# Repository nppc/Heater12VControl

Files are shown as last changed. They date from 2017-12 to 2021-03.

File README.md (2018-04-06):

# uReflow Station
Micro Reflow Station with 12V heating ceramic element and temperature PID control.

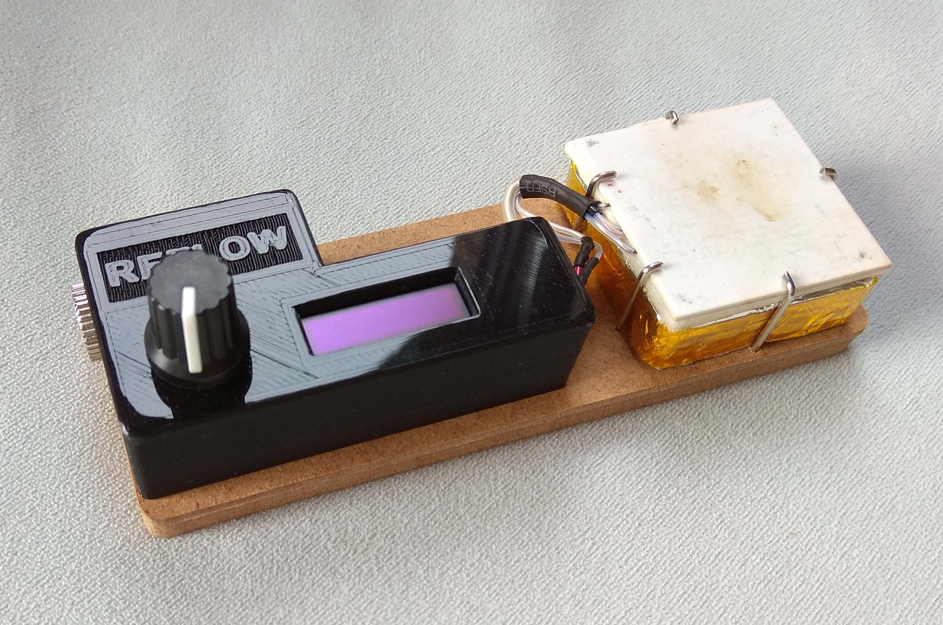
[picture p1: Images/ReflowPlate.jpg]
Device assembled

The device is only 13cm long. Heating plate is 4x4cm. Power is 12VDC.

## 2 modes of operation: Manual and Automatic.
In Manual mode preset temperature is maintained. The temperature can be adjusted on the fly.
In Automatic mode the device is following general reflow thermal profile.

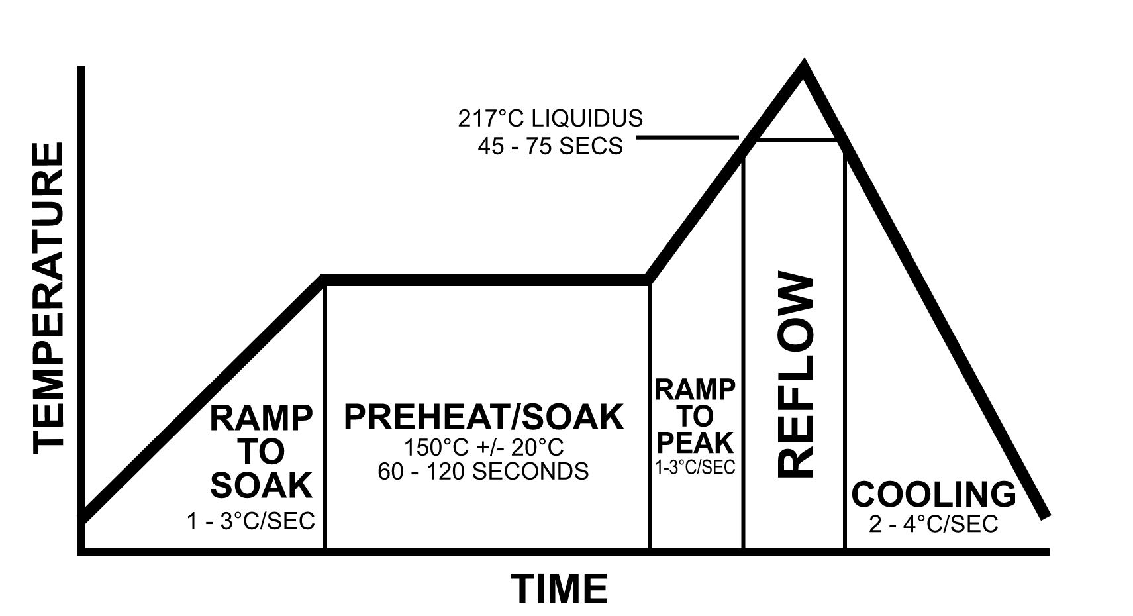
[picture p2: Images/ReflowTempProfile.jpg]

Example of reflow soldering thermal profile (from Wikipedia)

Every parameter can be adjusted (Soak and reflow temperature and time). Preset can be configured and stored in EEPROM and can be adjusted on the fly.

### We will need:
- 1 Heating element like XD-JR80 12V48W
- 1 Thermistor 100K NTC 3950 (from 3D printer)
- 1 Arduino Nano
- 1 Rotary Encoder like EC11
- 1 OLED 128x32 with I2c
- 1 P-Mosfet like AON6403, AON6411, AON7423 or similar.
- And some other smd components
- PCB from OSHPark: https://oshpark.com/shared_projects/yKbu7gQC

I have added to the firmware support for K type thermocouple (MAX31855 or MAX6675), but made no PCB for this. I left it up to your creativity. :)

Controller board (OLED, rotary encoder, mosfet control and thermistor monitor):
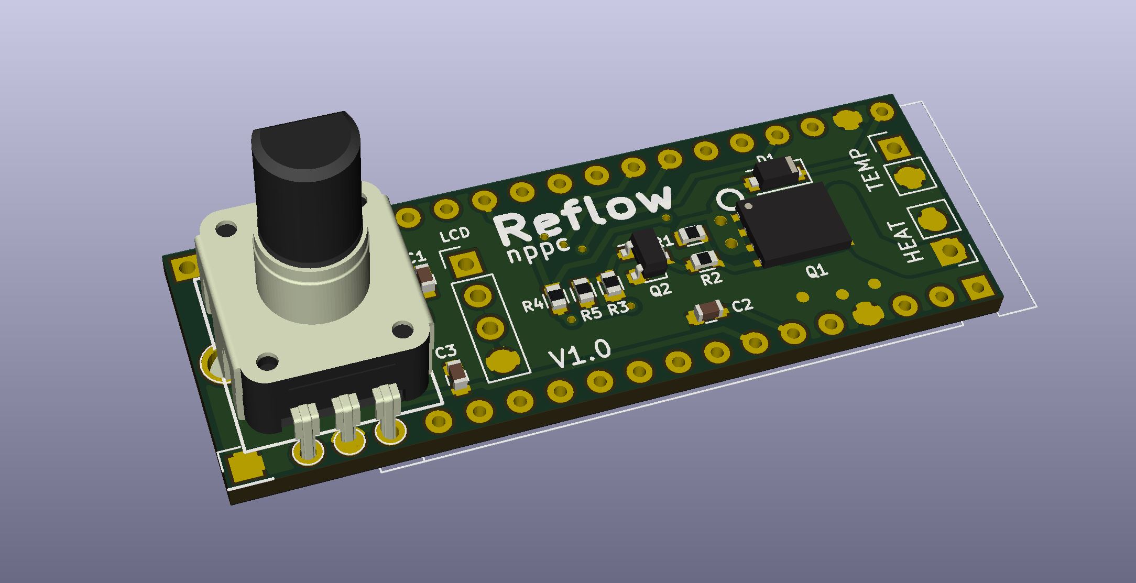
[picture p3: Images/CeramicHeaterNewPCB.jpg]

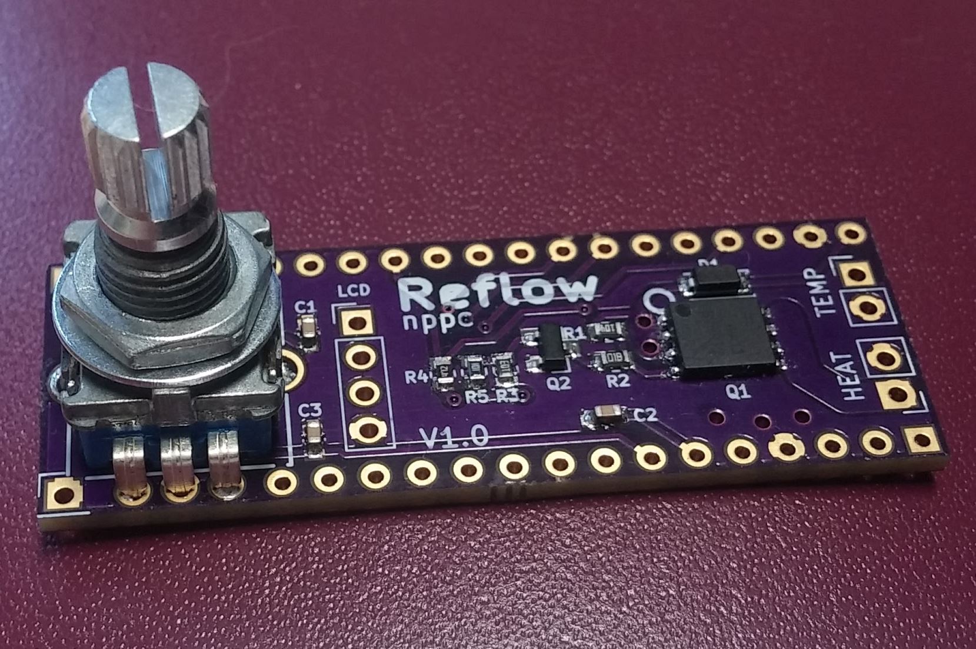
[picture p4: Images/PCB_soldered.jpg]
PCB soldered


## LCD screens snapshots:
### Start menu 
(choose two presets - manual temperature regulation or automatic reflow)
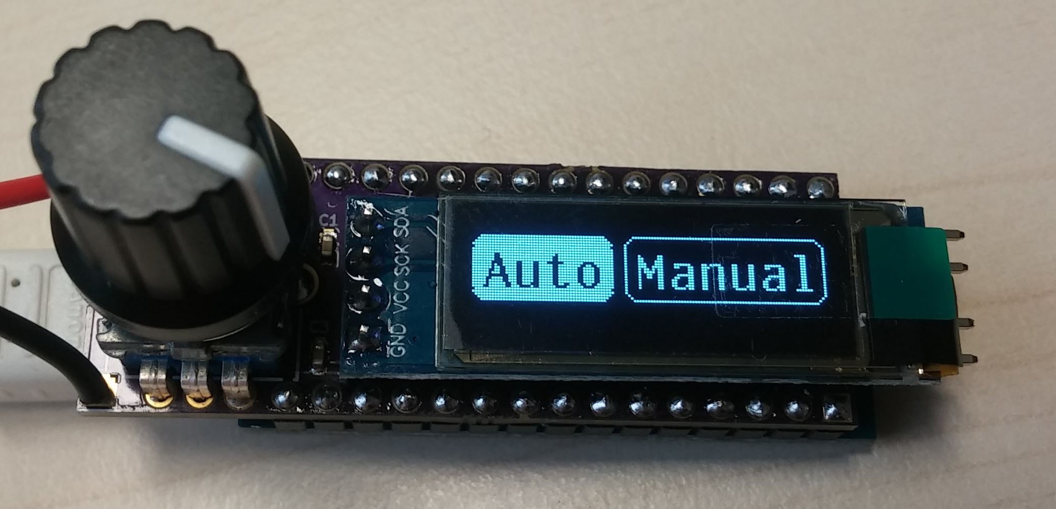
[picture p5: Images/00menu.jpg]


### Manual mode 
- Target temperature is adjustable on the fly. 
- Timer is counting total time while on target temperature.
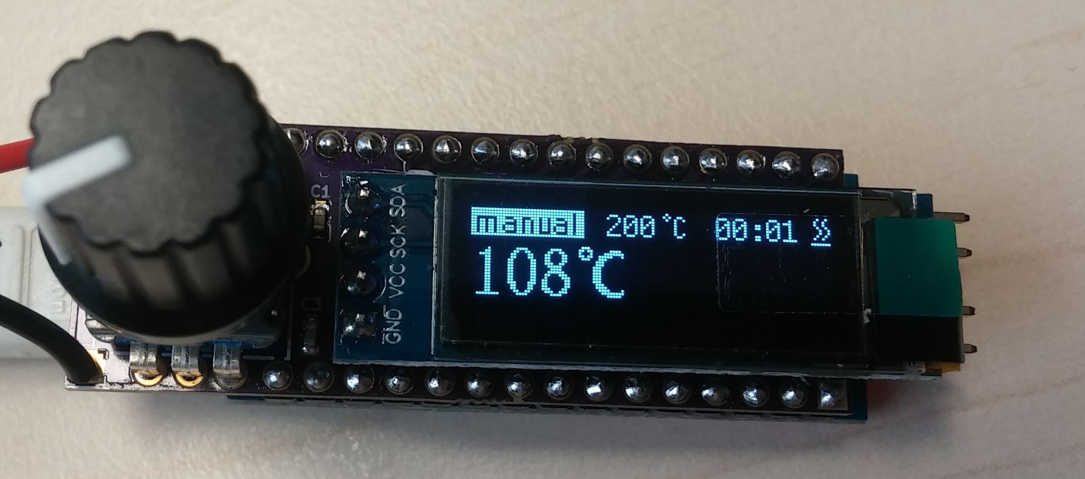
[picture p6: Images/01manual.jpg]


### Automatic Reflow mode
- Indication of current step (soak, reflow, cooling)
- Timer for every step
- Target temperature and time is adjustable on the fly. 

(Ramp to soak step)
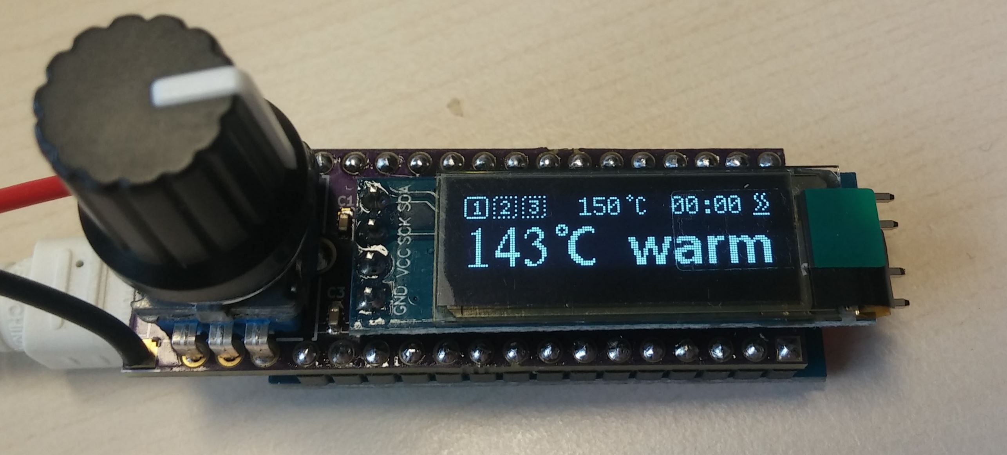
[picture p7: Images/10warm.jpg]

(Soak step - preheating)
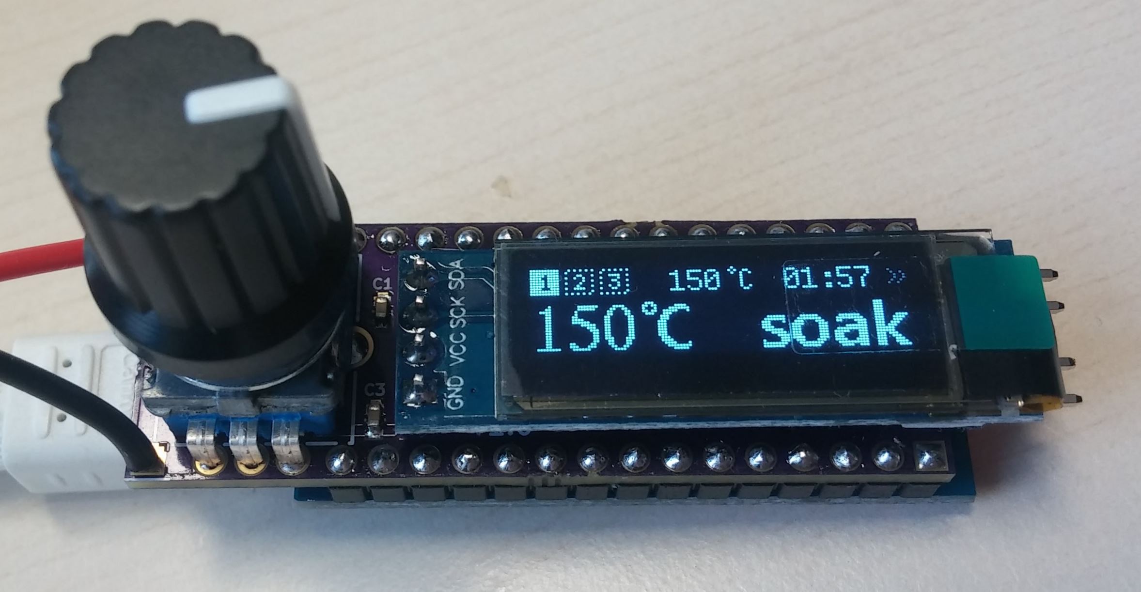
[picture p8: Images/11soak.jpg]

(Ramp to reflow step)
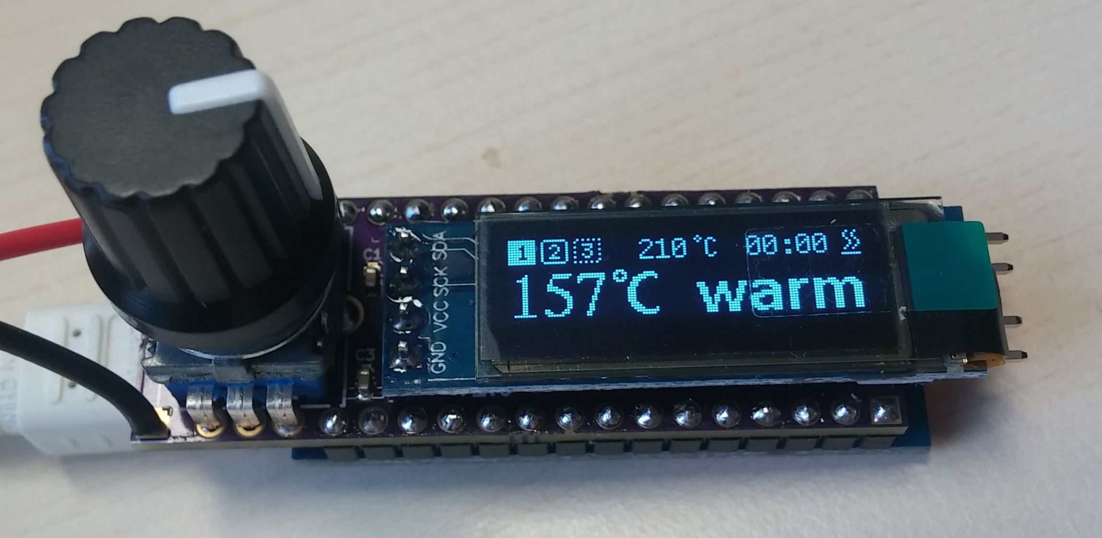
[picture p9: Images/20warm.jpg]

(Reflow step)
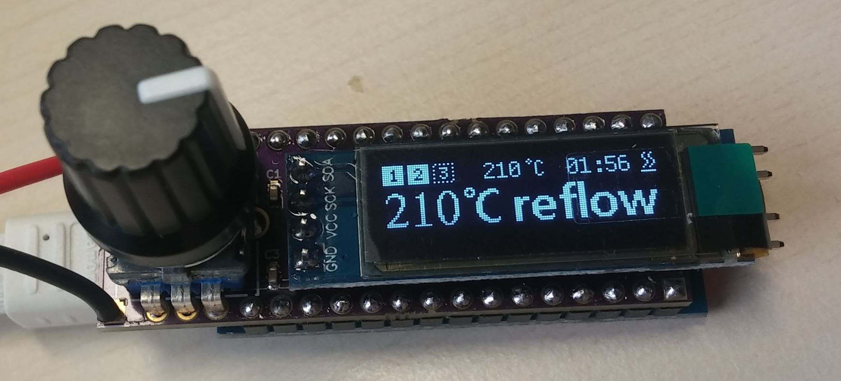
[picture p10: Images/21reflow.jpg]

(Cooling down step)
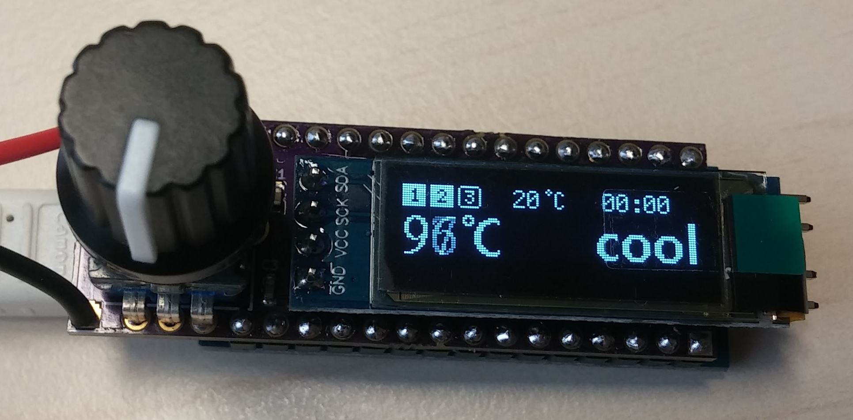
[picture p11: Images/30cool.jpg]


## Configurable parameters
(long button press while in start menu)
- PID P
- PID I
- PID D
- Soak temperature (preheating)
- Soak time (preheating)
- Reflow temperature
- Reflow time
- Target temperature for Manual mode

## Compiling with Arduino
You can use latest Arduino IDE.
And need to include two libraries via Arduino IDE Libraries Manager
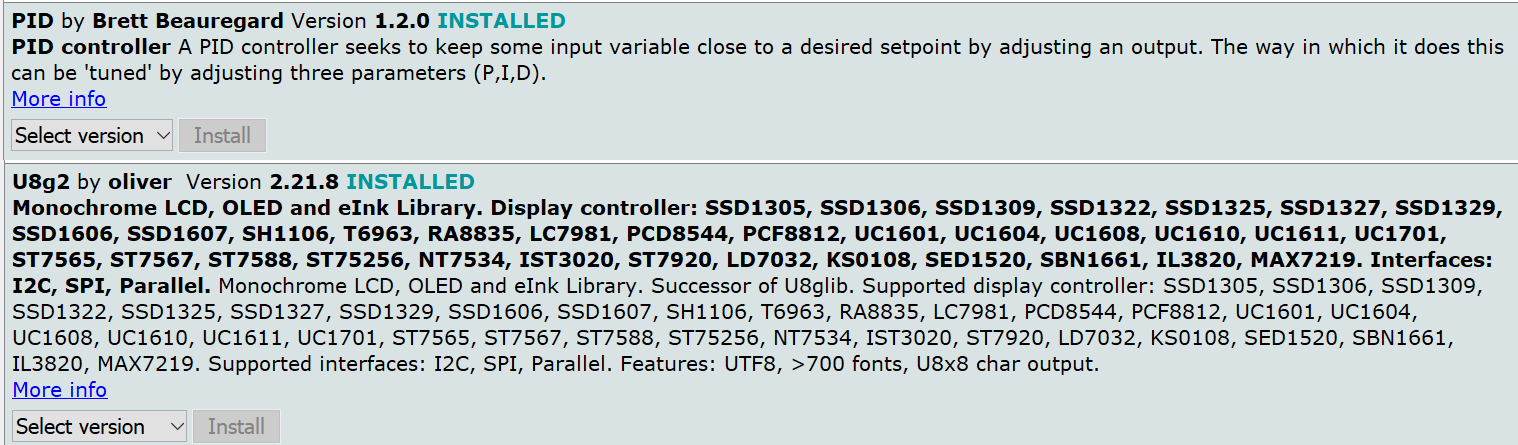
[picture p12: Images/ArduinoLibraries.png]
Arduino Libraries


Discussion here: https://www.rcgroups.com/forums/showthread.php?2998269-DIY-reflow-soldering-ceramic-plate

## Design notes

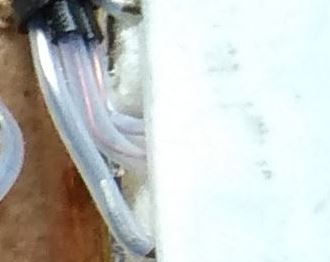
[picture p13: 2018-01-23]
Images/Thermistor.jpg

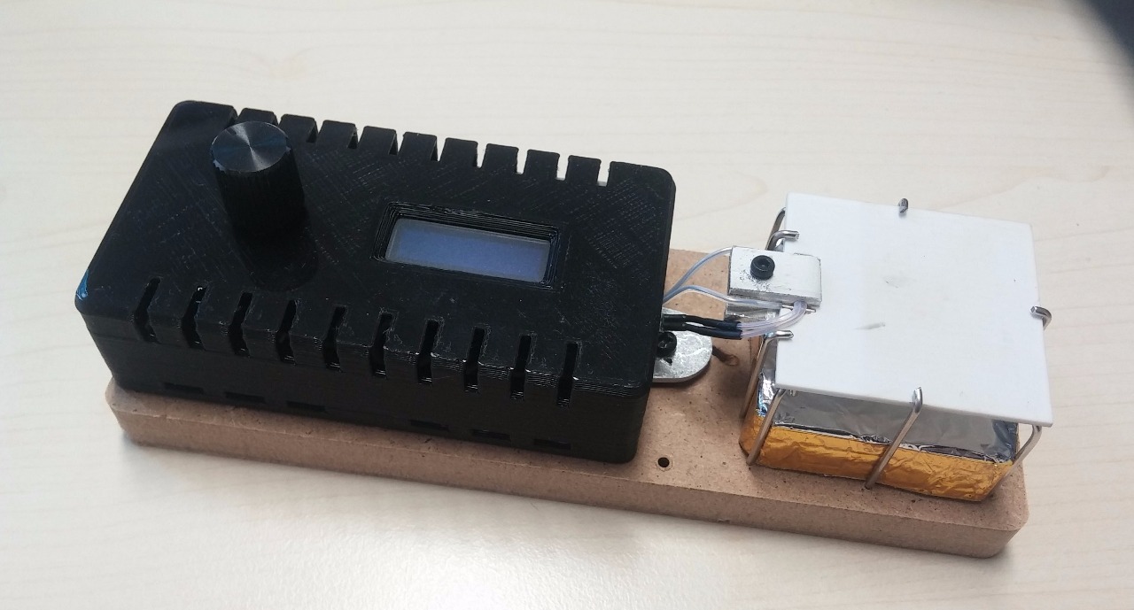
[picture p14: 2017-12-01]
Images/ReadyDEvice.jpg

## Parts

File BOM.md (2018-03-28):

## Bill of Materials

Symbol | Component | Package | Mouser Part No
---- | ------------ | ------------ | ------------
Q1 | AON6403 or similar | DFN5X6 | 757-TPH1R712MDL1Q
Q2 | SI2312 or similar | SOT23 | 781-SI2312CDS-T1-GE3
R1 | 100K | SMD 0603 | 603-RC0603FR-07100KL
R2 |   1K | SMD 0603 | 603-RC0603FR-071KL
R3 |  10K | SMD 0603 | 603-RC0603FR-0710KL
R4 | 4.7K | SMD 0603 | 603-RC0603FR-074K7L
R5 |  100 | SMD 0603 | 603-RC0603FR-07100RL
C1 | 10n-40n | SMD 0603 | 710-885012206016
C2 | 10n-40n | SMD 0603 | 710-885012206016
C3 | 10n-40n | SMD 0603 | 710-885012206016
D1 | B5819W or similar diode or schottky | SMD SOD-123 | 833-B5819W-TP
SW1 | Rotary Encoder EC11 | | Ebay, Aliexpress or Banggood 
Display | OLED 128x32 with I2c | | Ebay, Aliexpress or Banggood 
Heating Plate | XD-JR80 12V48W | | Ebay, Aliexpress or Banggood

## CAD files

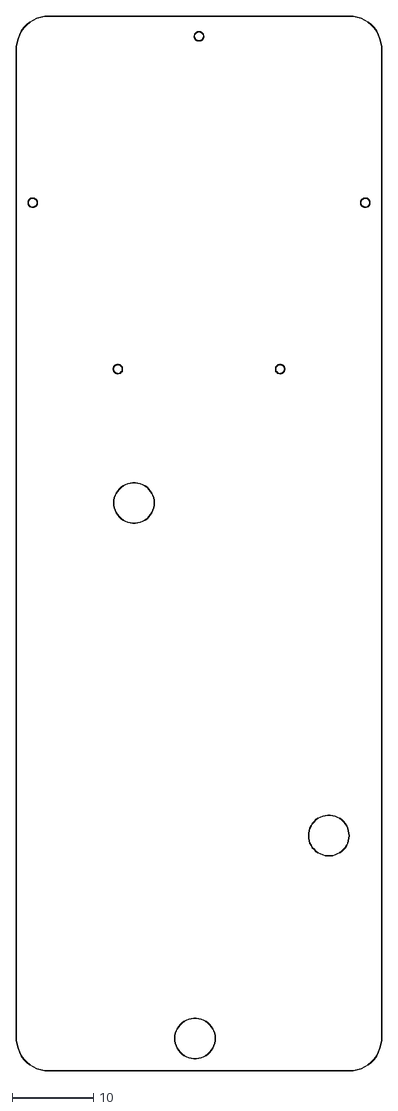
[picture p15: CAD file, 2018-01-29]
SCAD/BoxBase.dxf
45.0 x 130.0

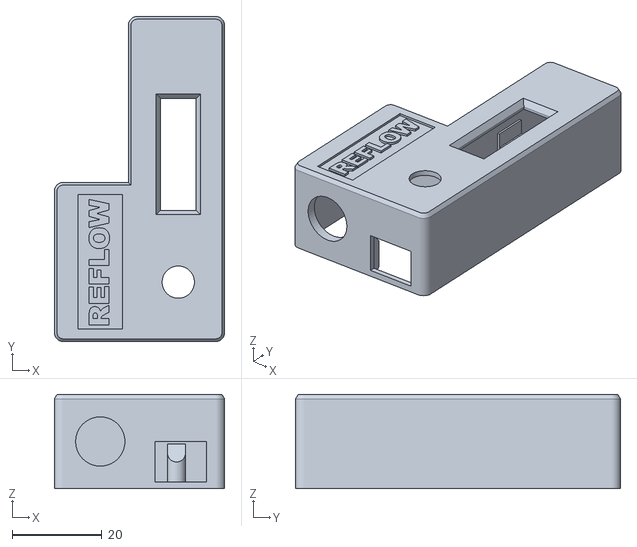
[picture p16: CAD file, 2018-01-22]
SCAD/Box.stl
38.0 x 72.5 x 21.0

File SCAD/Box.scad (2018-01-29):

$fn=50;

/*
Box();
translate([-7.5,-33,-5])case_mountinghole();
translate([-24,-8,-5])rotate([0,0,-90])case_mountinghole();
translate([0,33,-5])rotate([0,0,180])case_mountinghole();

translate([-15,-33,10.5])rotate([0,0,90])linear_extrude(height = 0.5){text("REFLOW", $fn = 20, size = 4.5, font = "ArialBlack");}
*/

smallHole=1.13;
projection(cut=false)rotate([180,0,90])heaterBase();
//translate([-8,28,-20])rotate([180,0,90])heaterBase();


module Box(){
difference(){
    union(){
        difference(){
            union(){
                generalBox(21.5,72.5,21,4);
                translate([-17,-18.5,0])generalBox(20.5,35.5,21,4);
            }
            translate([0,0,-0.7])generalBox(19,70,20,2.6);
            translate([-17,-18,-0.7])generalBox(18,32,20,2.6);

            // cutout for PowerJack
            translate([-17,-11,0.5])rotate([90,0,0])cylinder(d=11,h=30);

            // cutout for encoder pin
            translate([0.4,-23,9]){
                cylinder(d=7.2,h=20);
                translate([6,0,0])cube([2,4,3.5], center=true);
            }

            // Cutout for USB
            translate([1,-35,-4])cube([11.5,10,9], center=true);

            // cutout for cables
            translate([0.4,35,4])cube([14,10,6], center=true);
            //cube([50,50,50]);

            // cutout for text
            translate([-17,-18.5,11.5])cube([10,30,2], center=true);
        }
        // frame for OLED
        translate([0.4,-23+15+25/2+1,9.4])cube([10,27,1], center=true);
        
        // PCB holders
        translate([9,20,9.2-12]){
            rotate([90,0,0])cylinder(d=1.5,h=8,center=true);
            translate([0,-4,-0.75])cube([1,8,5]);
        }
        translate([-9,20,9.2-12]){
            rotate([90,0,0])cylinder(d=1.5,h=8,center=true);
            translate([-1,-4,-0.75])cube([1,8,5]);
        }
   }
    // cutout for OLED
    translate([0.4,-23+15+25/2+1,9]){
        
        cube([8,25,5], center=true);
        hull(){
            translate([0,0,3])cube([11,28,0.1], center=true);
            translate([0,0,2])cube([8,25,3], center=true);
        }
    }
}
}



module generalBox(sx,sy,sz,diam){
    hull(){
        translate([(sx-diam)/2,(sy-diam)/2,0])generalBoxCylinder(sz,diam);
        translate([(-sx+diam)/2,(sy-diam)/2,0])generalBoxCylinder(sz,diam);
        translate([(sx-diam)/2,-(sy-diam)/2,0])generalBoxCylinder(sz,diam);
        translate([-(sx-diam)/2,-(sy-diam)/2,0])generalBoxCylinder(sz,diam);
    }
}

module generalBoxCylinder(hght,diam){
    cylinder(d=diam, h=hght-1,center=true);
    translate([0,0,(hght-1)/2])cylinder(d1=diam,d2=diam-1.2, h=1);
}


module case_mountinghole(){
    rotate([0,180,0])difference(){
        hull(){
            cylinder(d=4, h=10, center=true);
            translate([0,-2,0])cube([4,2,10], center=true);
        }
        translate([0,0,3])cylinder(d=1.8, h=9, center=true);
        translate([0,2,-8])rotate([45,0,0])cube([15,15,10], center=true);
    }
}

module heaterBase(){
    color("BROWN")difference(){
        hull(){
            translate([130/2-4,45/2-4,0])cylinder(d=8,h=10);
            translate([-130/2+4,45/2-4,0])cylinder(d=8,h=10);
            translate([130/2-4,-45/2+4,0])cylinder(d=8,h=10);
            translate([-130/2+4,-45/2+4,0])cylinder(d=8,h=10);
        }
        translate([42,0,0]){
            holesCeramicHold();
        }
        translate([-28,-8,0]){
            rotate([0,0,-90]){
                holesPlasticCase(40,2.5);
                holesPlasticCase(40,5);
            }
        }
    }
}


module holesCeramicHold(){
    translate([0,41/2,0])cylinder(d=smallHole,h=25, center=true);
    translate([-41/2,10,0])cylinder(d=smallHole,h=25, center=true);
    translate([0,-41/2,0])cylinder(d=smallHole,h=25, center=true);
    translate([-41/2,-10,0])cylinder(d=smallHole,h=25, center=true);
    translate([41/2,0,0])cylinder(d=smallHole,h=25, center=true);
}

module holesPlasticCase(hght,diam){
    translate([-7.5,-33,-5])cylinder(d=diam,h=hght, center=true);
    translate([-24,-8,-5])cylinder(d=diam,h=hght, center=true);
    translate([0,33,-5])cylinder(d=diam,h=hght, center=true);
}

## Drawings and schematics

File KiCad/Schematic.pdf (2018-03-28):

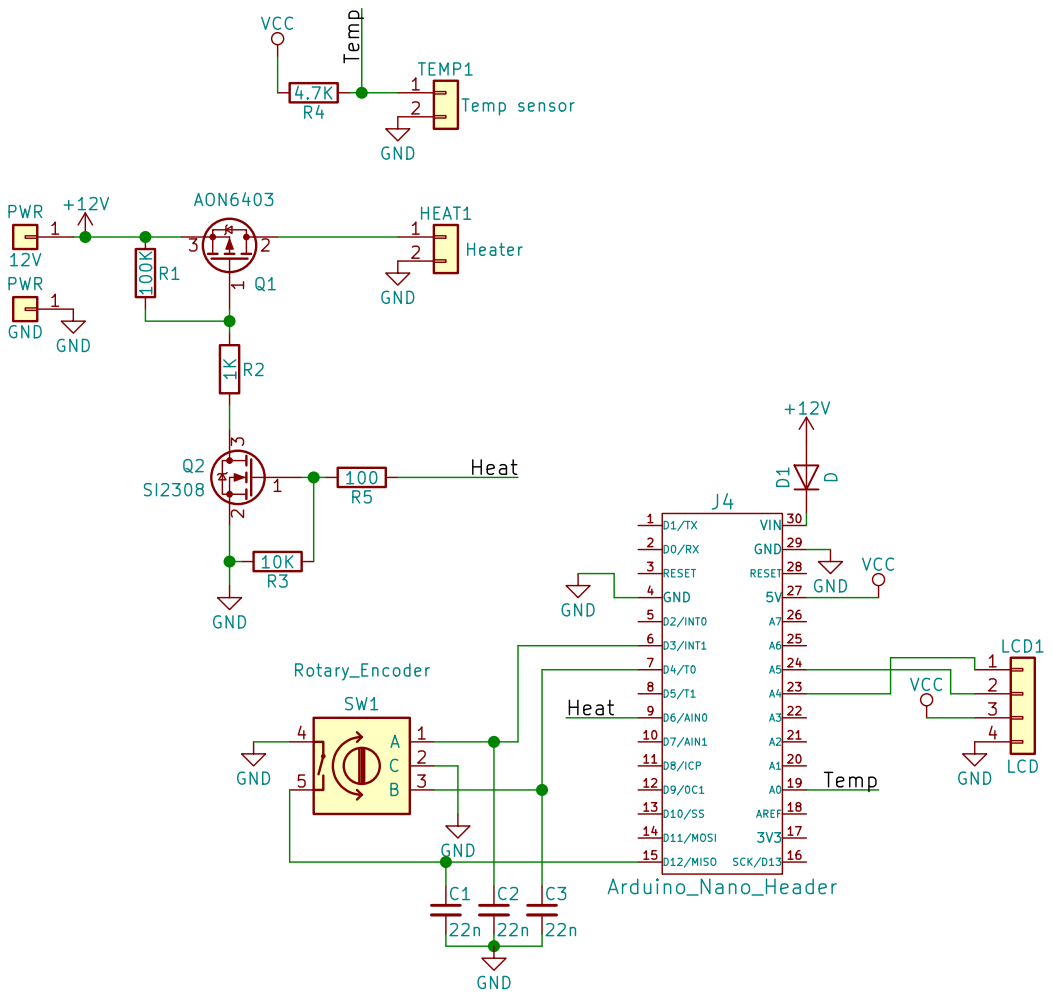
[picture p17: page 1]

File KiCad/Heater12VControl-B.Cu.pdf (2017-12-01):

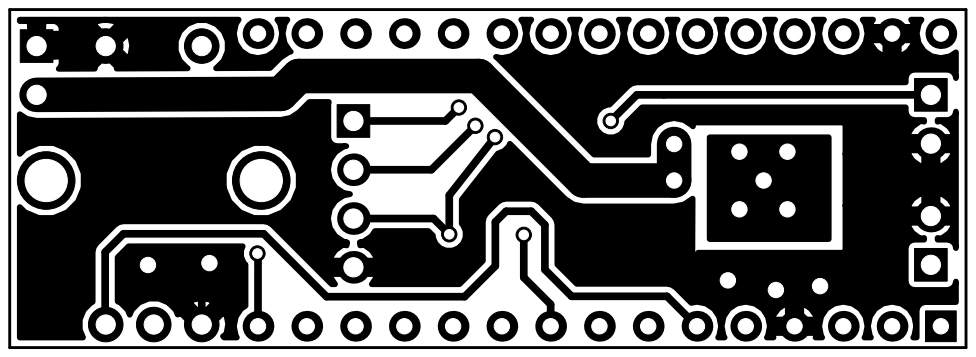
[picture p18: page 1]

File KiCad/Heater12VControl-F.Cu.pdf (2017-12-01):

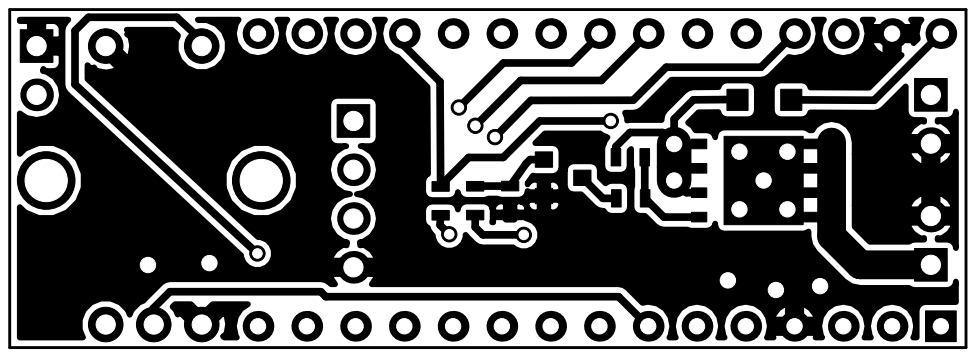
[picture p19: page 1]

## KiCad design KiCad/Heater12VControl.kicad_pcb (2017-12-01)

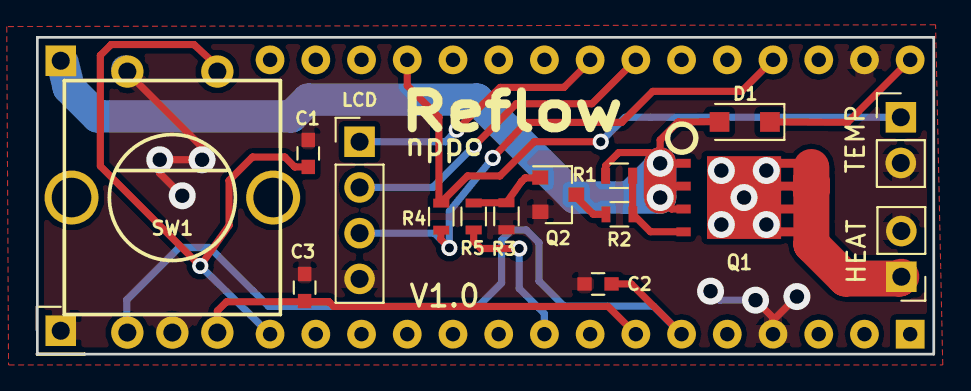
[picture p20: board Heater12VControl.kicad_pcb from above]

Board: 2 copper layers, 49.8 x 17.6 mm, 18 parts (1 on the bottom side), 15 nets.

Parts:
12V: PWR; Pin_Header_Straight_1x01_Pitch2.54mm
C1, C2, C3: 22n; C_0603
D1: D; D_SOD-123F
GND: PWR; Pin_Header_Straight_1x01_Pitch2.54mm
HEAT: Heater; Pin_Header_Straight_1x02_Pitch2.54mm
J4: Arduino_Nano_Header; Arduino_Nano
LCD: LCD; Pin_Header_Straight_1x04_Pitch2.54mm
Q1: AON6403; DFN-8-1EP_6x5mm
Q2: SI2308; SOT-23
R1: 100K; R_0603
R2: 1K; R_0603
R3: 10K; R_0603
R4: 4.7K; R_0603
R5: 100; R_0603
SW1: Rotary_Encoder; ROTARY-ENCODER
TEMP: Temp sensor; Pin_Header_Straight_1x02_Pitch2.54mm

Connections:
+12V: 12V.1, D1.2, Q1.3, R1.1
/Heat: J4.9, R5.1
/Temp: J4.19, R4.1, TEMP.1
GND: C1.2, C2.2, C3.2, GND.1, HEAT.2, J4.4, J4.29, LCD.4, Q2.2, R3.2, SW1.2, SW1.4, TEMP.2
unnamed: C1.1, J4.15, SW1.5
unnamed: C2.1, J4.6, SW1.1
unnamed: C3.1, J4.7, SW1.3
unnamed: D1.1, J4.30
unnamed: HEAT.1, Q1.2
unnamed: J4.23, LCD.1
unnamed: J4.24, LCD.2
unnamed: Q1.1, R1.2, R2.1
unnamed: Q2.1, R3.1, R5.2
unnamed: Q2.3, R2.2
VCC: J4.27, LCD.3, R4.2

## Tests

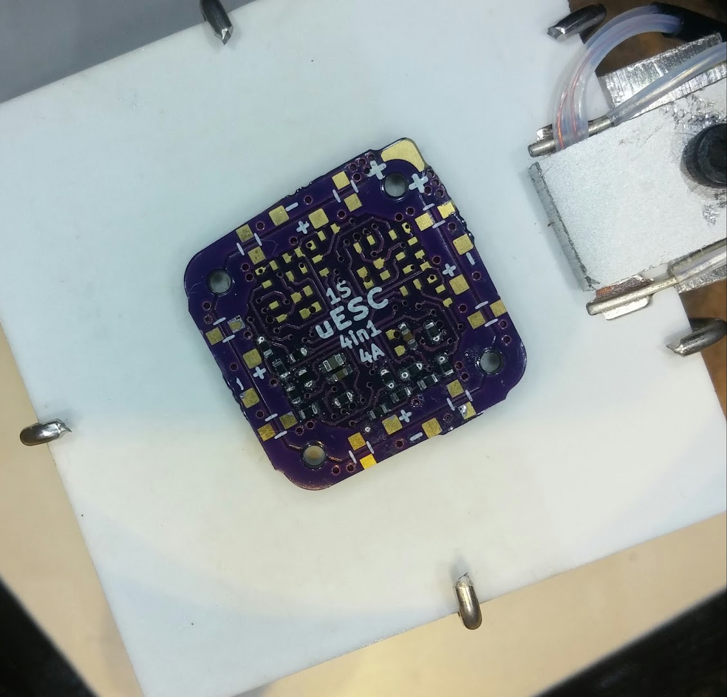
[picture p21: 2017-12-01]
Images/TestPCB.jpg

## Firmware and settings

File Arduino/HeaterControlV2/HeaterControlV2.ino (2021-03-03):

//*********************
// * HW CONFIGURATION *
//*********************
//#define DEBUG	// output the results to Serial

// Enable only one of the temperature sensors
//#define MAX31855
//#define MAX6675
#define NTC // using Temperature table

#define OLED	// Use OLED display
//#define VIRTUALTEMPERATURE	//For debug purposes, when temp sensor is disconnected
//#define SOFTRESET	// If your Arduino has broken bootloader (watchdog is not working) then enable this dirty trick or better - flash optiboot to your arduino.
//#define TIMER_MINUTES // Count in minutes/hours. If not defined then seconds/minutes
//*********************

#include "encoder.h"
#include "adc.h"
#include <PID_v1.h>
#include <EEPROM.h>
#include "eeprom.h"
#include <avr/wdt.h>

#ifdef OLED
	#include <U8g2lib.h>
	#include "oled.h"
#endif



#define MOSFET_PIN 		6
#define LED_PIN 		13
#define TEMPSENSOR_PIN 	A0

#define encoderPinA   3	// Interrupt pin (coupled with capacitor to GND)
#define encoderPinB   4 // Interrupt pin (coupled with capacitor to GND)
#define BUTTON_PIN   12 // Pin for knob button

#define FAN_PIN   2 // FAN for cooling stage


// RAMP can always be 3 deg per second

#ifdef TIMER_MINUTES
  #define TIMER_DIVIDER (uint16_t)(1000 * 60)
#else
  #define TIMER_DIVIDER 1000
#endif

// ADC=1023 - temp sensor is not connected

// some macros: 
// mosfet (HIGH - OFF, LOW - ON)
#define H_ON 	digitalWrite(MOSFET_PIN,HIGH);digitalWrite(LED_PIN, HIGH);
#define H_OFF 	digitalWrite(MOSFET_PIN,LOW);digitalWrite(LED_PIN, LOW);

uint8_t ControlType;		// 0 - Manual or 1 - Auto
//uint8_t ProcessStage;		// 0 - just hold manual temperature; 1 - Ramp to Preheat; 2 - Preheat; 3 - Ramp to Reflow; 4 - Reflow; 5 - Cool down; 255 - finished

// PID global variables
#define PID_WINDOWSIZE 500	// upper limit of PID output
#define PID_ABSTEMPDIFFERENCE 10	// Difference in set and current temperature when PID should not work.
#define PID_P_FACTOR 1.0	//PID values are stored in EEPROM in int format. So, scale them (div) before use.
#define PID_I_FACTOR 10.0	//PID values are stored in EEPROM in int format. So, scale them (div) before use.
#define PID_D_FACTOR 1.0	//PID values are stored in EEPROM in int format. So, scale them (div) before use.

double currentTemp=0;
double setPoint=0;
double outputVal;

int pid_P, pid_I, pid_D; // PID values
int auto_preheatTemp, auto_preheatTime, auto_reflowTemp, auto_reflowTime, manual_temp;

unsigned long soft_pwm_millis;

//input/output variables passed by reference, so they are updated automatically
PID myPID(&currentTemp, &outputVal, &setPoint, 0, 0, 0, DIRECT); // PID values will be set later

unsigned long timer_millis;
int timer_counter;
boolean timer_active=false;
uint8_t value_editable=0;	// Edit Preset temperature or Timer on the fly (0 - nothing editable, 1 - Preset Temp, 2 - Timer)
unsigned long value_editable_millis;


#ifdef DEBUG
	unsigned long serial_ms = 0;
#endif

#ifdef VIRTUALTEMPERATURE
	unsigned long virtualTemperature_ms = 0;
	boolean virtualTemperature_Direction = true;
#endif

void setup(){
	
	wdt_disable();
	pinMode(MOSFET_PIN,OUTPUT);
	pinMode(LED_PIN,OUTPUT);
  pinMode(FAN_PIN,OUTPUT);
  digitalWrite(FAN_PIN,LOW);
	H_OFF

	#ifdef DEBUG
		Serial.begin(115200);
	#endif
	
	#ifdef OLED
		u8g2.begin();
		u8g2.setDrawColor(2);	// Xor is default mode across all sketch.
		u8g2.setFontMode(1);	// Or is default mode
	#endif
	
	Temperature_init();
		
	#ifdef DEBUG
		Serial.print(F("Temperature Sensor: "));
		Serial.println(getTemperature());
	#endif
	
	// read PID values from EEPROM
	restore_settingsEEPROM();
	// we use FACTOR for PID values to get rid of comas in interface.
	myPID.SetTunings((float)pid_P / PID_P_FACTOR,(float)pid_I / PID_I_FACTOR,(float)pid_D / PID_D_FACTOR);
	myPID.SetOutputLimits(0, PID_WINDOWSIZE);	//set PID output range

	initEncoder();
		
	waitUntilButtonReleased(); // in case it was

	// main screen (choose Manual/Auto)
	#ifdef OLED
	drawMenu_AutoManual(ControlType);
	#endif
	#ifdef DEBUG
	Serial.print(F("ControlType is: "));Serial.println(ControlType);
	#endif
	char encVal = 0;  // signed value - nothing is pressed
	while (encVal != 127) {
		#ifdef OLED
		drawMenu_AutoManual(ControlType);
		#endif
		encVal = rotaryEncRead();
		if(encVal!=127 && encVal!=0) {
			if(encVal>0){ControlType=0;}else{ControlType=1;}
			#ifdef DEBUG
			Serial.print(F("ControlType is: "));Serial.println(ControlType);
			#endif
		}
		currentTemp = getTemperature();
	}
	EEPROM.update(EEPROM_CONTROLTYPE,ControlType);	// store selected Control Type for the next time
	#ifdef OLED
	u8g2.clearDisplay();
	#endif
	// wait until button released
	encoderLongPressmillis=millis();
	while(rotaryEncRead() == 127){
		if(is_rotaryEncLongPress()){
			// go to config menu
			configureParams();
			encoderLongPressmillis=millis();
		}
	}	

	if(ControlType==0){
		setPoint=manual_temp;	// last saved temperature.
		#ifdef DEBUG
		Serial.println(F("Start Manual mode"));
		#endif
	}else{
		setPoint=auto_preheatTemp;
		#ifdef DEBUG
		Serial.println(F("Start Automatic mode"));
		#endif
	}

	timer_counter=0;
	timer_active=false;

	myPID.SetMode(AUTOMATIC); // turn on PID
	
	
	#ifdef VIRTUALTEMPERATURE
		currentTemp=setPoint-PID_ABSTEMPDIFFERENCE*2;
	#endif
	
	soft_pwm_millis = millis()-50000;	// Before turning on the heater wait for some seconds
		
}

void loop() {
	
	// Exit by holding button for 2 seconds...
	WDT_Init();	// keep system alive
	
	#ifdef VIRTUALTEMPERATURE
	if (virtualTemperature_ms+TIMER_DIVIDER < millis()) {
		virtualTemperature_ms = millis();
		currentTemp += (virtualTemperature_Direction ? 0.4: -0.4);
		if(virtualTemperature_Direction && currentTemp>setPoint+PID_ABSTEMPDIFFERENCE){virtualTemperature_Direction=false;}
		if(!virtualTemperature_Direction && currentTemp<setPoint-PID_ABSTEMPDIFFERENCE-1){virtualTemperature_Direction=true;}
	}
	#else
	currentTemp = getTemperature();
	#endif

	
	// use PID only when difference is small (to prevent windup of I)
	if(abs(setPoint-currentTemp)<PID_ABSTEMPDIFFERENCE){
		myPID.Compute();
	}else{
		outputVal = (setPoint > currentTemp ? PID_WINDOWSIZE : 0); // ON/OFF control
	}
	doSoftwarePWM((uint16_t)outputVal);	// make slow PWM to prevent unnecessary mosfet heating 

	if(ControlType==0){
		adjustValues(1);	//adjust values on the fly (only preset temp to adjust)
		doManualReflow();
	}else{
		adjustValues(2);	//adjust values on the fly (adjust both, preset temp and timer)
		doAutoReflow();
	}
	
	// debug 
	#ifdef DEBUG
	if (serial_ms+1000 < millis()) {
		serial_ms = millis();
		Serial.print(F("Set: "));Serial.print(setPoint);
		Serial.print(F(", Actual: "));Serial.print(currentTemp);
		Serial.print(F(", PWM: "));Serial.print(outputVal);
		Serial.print(F(", Timer: "));Serial.println(timer_counter);
	}	
	#endif	
	
	// increment or decrement timer
	if(timer_millis+TIMER_DIVIDER<millis()) {
		uint16_t seconds_passed=(uint16_t)((unsigned long)(millis()-timer_millis)/TIMER_DIVIDER);
		timer_millis=millis();
		if(timer_active){timer_counter+=(ControlType==0 ? seconds_passed : -seconds_passed);} // increment only in manual mode.
	}

}


// PWM output 
void doSoftwarePWM(uint16_t pwm_val){
	if (millis() - soft_pwm_millis > PID_WINDOWSIZE)
	  { //time to shift the Relay Window
		soft_pwm_millis += PID_WINDOWSIZE;
	  }
	if (pwm_val < millis() - soft_pwm_millis){H_OFF}else{H_ON}
		
}

void doManualReflow(){
	// draw screen
	#if defined (OLED)
	u8g2.clearBuffer();
	printManual();

	if(value_editable==1){
		u8g2.drawBox(46,0,33,10);
	}

	printPresetTemperature();
	printTime(timer_counter);
	printCurrentTemperature();

	inlineLogger_fill();
	inlineLogger_draw();
		
	printHeaterState(); //print icon of the heater ON/OFF state

	u8g2.sendBuffer();
	#endif
	
	if(currentTemp>=(setPoint-2)){timer_active=true;} else {timer_active=false;}	// Timer running if temperature near or reached preset temp.
}

void doAutoReflow(){
	// process current step (variable ControlType)
	switch (ControlType) {
		case 1:	// ramp to preheat temperature
			// setpoint is already set...
			// wait until temperature is reached the auto_preheatTemp. Then go to the next step
			if(currentTemp>=(setPoint-2)){
				timer_counter=auto_preheatTime;
				timer_active=true;
				timer_millis = millis(); // reset timer
				ControlType=2;	// go to the next step
			}
			break;
		case 2:	// wait for timer
			if(timer_counter<=0){
				timer_counter=0;
				timer_active=false;
				setPoint=auto_reflowTemp;	// set temperature for next step
				ControlType=3;	// go to the next step
			}
			break;
		case 3:	// ramp to reflow temperature
			// wait until temperature is reached the auto_preheatTemp. Then go to the next step
			if(currentTemp>=(setPoint-2)){
				timer_counter=auto_reflowTime;
				timer_active=true;
				timer_millis = millis(); // reset timer
				ControlType=4;	// go to the next step
			}
			break;
		case 4:	// wait for timer
			if(timer_counter<=0){
				timer_counter=0;
				timer_active=false;
				setPoint=20;	// Cool down
				digitalWrite(FAN_PIN,HIGH);
				ControlType=5;	// go to the next step
			}
			break;
		case 5:	// wait for cooling down
			if(currentTemp<50){
				//ControlType=6; // on the next step do nothing
				digitalWrite(FAN_PIN,LOW);
				while(1){}	// reboot board - exit to menu
			}	
	}	

	#ifdef OLED
	u8g2.clearBuffer();
	printAuto();
	if(value_editable==1){
		u8g2.drawBox(46,0,33,10);
	}else if(value_editable==2){
		u8g2.drawBox(85,0,33,10);
	}
	printPresetTemperature();
	printTime(timer_counter);
	printCurrentTemperature();
	printHeaterState(); //print icon of the heater ON/OFF state
	
	printStepTextGraphic();

	u8g2.sendBuffer();
	#endif
}

void adjustValues(uint8_t vals) {
	int val_adjust=0;	// for adjusting temperature or time on the fly
	char encVal = 127;  // signed value - just enter to the loop
	while (encVal == 127) { //loop here while button is pressed (waiting longer than 2 seconds will reset the board (Exit to the init menu).
		encVal = rotaryEncRead();
		if(encVal!=127 && value_editable>0) {
			val_adjust = encVal;
		}else if(encVal==127){
			H_OFF	// turn off heater, because we will freeze here for some time...
			waitUntilButtonReleased();
			value_editable++;	// change edit mode
			if(value_editable>vals){value_editable=0;}
			value_editable_millis=millis();		// start timer for edit time within 3 seconds
		}
	}
	// adjust current temperature or timer
	if(val_adjust!=0 && ControlType<5){
		val_adjust*=10; // adjust in 10's steps
		if(value_editable==2){
			timer_counter=constrain(timer_counter+val_adjust,0,990);
		}else if(value_editable==1){
			setPoint=constrain((int)setPoint+val_adjust,20,300);
		}
		value_editable_millis=millis();
	}
	// reset timer_editable flag if edit time expired
	if(value_editable>0 && value_editable_millis+3000<millis()) {value_editable=0;}
}	

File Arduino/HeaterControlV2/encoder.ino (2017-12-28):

// Encoder routines. Uses one Interrupt.

void initEncoder() {    
	pinMode(encoderPinA, INPUT_PULLUP); 
    pinMode(encoderPinB, INPUT_PULLUP); 
    pinMode(BUTTON_PIN, INPUT_PULLUP); 
    attachInterrupt(1, INT_doEncoder, FALLING);  // encoder pin on interrupt 1 - pin 3
}

char rotaryEncRead() {
  noInterrupts();
  char tmp = encoderPos;
  encoderPos=0;  // reset encoder
  interrupts();
  if(!digitalRead(BUTTON_PIN)){tmp=127;} // read button
  return tmp;
}

void INT_doEncoder() {
    // If interrupts come faster than 5ms, assume it's a bounce and ignore
    if (millis() - encodermillis > 5) {
        if (!digitalRead(encoderPinB))
            encoderPos++;
        else
            encoderPos--;

		has_encoderChange = HIGH;
        }
    encodermillis = millis();
}

// determine if rotary encoder was pressed longer than 2 seconds
bool is_rotaryEncLongPress() {
	 if(digitalRead(BUTTON_PIN)){
		 // button is not pressed
		 encoderLongPressmillis=millis();
	 }else{
		 // button is pressed
		 // how long?
		 if((encoderLongPressmillis+2000)<millis()){
			 // Long press engaged
			 return true;
			 encoderLongPressmillis=millis();	// reset counter
		 }
	 }
	 return false;
}

void waitUntilButtonReleased(){
	// wait until button is depressed
	while(rotaryEncRead() == 127){}
	delay(50); // wait for noise is gone from button contacts
}

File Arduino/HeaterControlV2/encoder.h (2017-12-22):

volatile char encoderPos = 0;	// accumulate encoder ticks in Interrupt.
volatile bool has_encoderChange = LOW;	// Indicates that Encoder has changed
unsigned long encodermillis = 0;
unsigned long encoderLongPressmillis = 0;

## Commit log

2017-10-02 Temperature table adjusted
2017-12-01 New Version with rotary encoder and AIO pcb
    [Heater12VControl.kicad_pcb, Heater12VControl.sch]
2017-12-27 Timer control in Manual Mode
2017-12-28 More Debug added. Some improvements in Encoder handling.
2017-12-28 PCB Image added
2017-12-31 Adjust PID range and values
2018-01-01 Fix bug with no sensor detection
    [HeaterControlV2.ino]
2018-01-17 Fixed Main and Configuration screen
    [HeaterControlV2.ino, config.ino, logger.ino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]
2018-01-18 Fixed major grphics bugs
    [HeaterControlV2.ino, logger.ino, oled.ino]
2018-01-18 Configure target temperature for Manual mode
2018-01-18 Adjust no sensor detection
2018-01-19 Start SCAD project for Heater box
    [Box.scad]
2018-01-19 Added temperature to main menu.
2018-01-21 Add OpenScad project
    [Box.scad, Box.stl]
2018-01-22 Final SCAD project. Box is ready
    [Box.scad, Box.stl]
2018-01-25 Add workaround for broken bootloader in some Arduinos
    [HeaterControlV2.ino, oled.ino]
2018-01-29 Added some images
    [Box.scad, BoxBase.dxf]
2018-03-27 BOM added
2018-03-27 BOM added Q2
2018-03-28 Schematic PDF added
2018-03-28 MOsfet Alternative added
2018-03-29 MAX pin assignment changed
2018-08-18 Added support for Fan on Cooling stage
2019-04-29 Fixed TIMER_DIVIDER define
2021-03-03 Update HeaterControlV2.ino
    Fix 32bit math calculation
    [HeaterControlV2.ino]
2021-03-03 Update HeaterControlV2.ino
    make sure define will be used correctly
    [HeaterControlV2.ino]
2021-03-03 Fix minutes (slow) counter
    [HeaterControlV2.ino]
